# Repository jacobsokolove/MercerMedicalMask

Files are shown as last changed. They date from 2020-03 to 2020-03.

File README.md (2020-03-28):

# MercerMedicalMask
Reusable 3D printed face mask

Mercer School of Engineering faculty and students have been working to fabricate reusable 3D printed face masks for use by medical professionals in locations where PPE supplies, such as N95 masks, have been depleted by the sharp increase in patient numbers (**link to earlier press release).  

Today, Dr. Joanna Thomas and Mercer engineering student Jacob Sokolove, with the help of Coliseum Medical Center physicians and nurses, put their mask prototype through a fit test (https://www.osha.gov/video/respiratory_protection/fittesting_transcript.html) to confirm its effectiveness.  

The prototype passed with flying colors so Mercer plans to move forward fabricating masks and distributing to medical facilities and medical practitioners that have indicated a need for alternative PPE as a stop gap measure for employees until FDA approved PPE becomes available again. A link to more information on the mask materials and the mask STL files is located below.     

**This mask was designed with efficacy and the wearer’s safety in mind. We selected materials we believe to be biocompatible based on available product data sheets; however, these masks are not FDA tested or approved and Mercer cannot guarantee their efficacy or safety. Anyone who fabricates these or similar masks and/or wears the masks we produce does so at their own risk.

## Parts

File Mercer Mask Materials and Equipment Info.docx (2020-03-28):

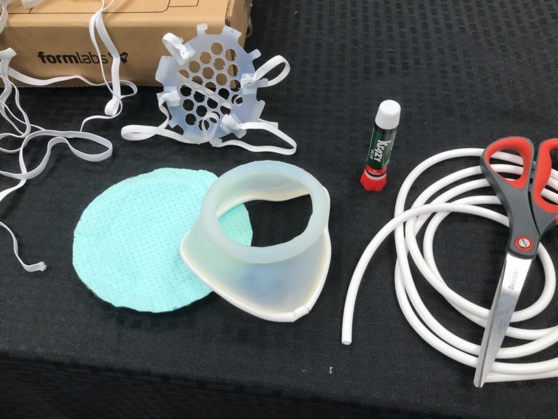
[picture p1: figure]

Mercer Mask Materials and Equipment Info

Formlabs Form2 or Form3 SLA printer

Formlabs Durable resin

405nm UV lights

Isopropanol

HEPA material

- This is what we are using https://www.homedepot.com/p/RIDGID-5-Layer-HEPA-Material-Pleated-Paper-Filter-for-Most-5-Gal-and-Larger-RIDGID-Wet-Dry-Shop-Vacuums-VF6000/100022800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

Elastic straps (strap holes in STL file are ~.3in w x .1in h)

Silicone rubber tubing

This is what we are using 1/8” ID, ¼” OD https://www.mcmaster.com/silicone-rubber-tubing

Our tested mask and clip were printed on a Formlabs Form2 SLA printer using Durable resin. We used .5 density for print supports with .5mm touchpoint size and mini rafts to attach to the print head. All prints were washed in >99% isopropanol for 20 min in a Form2 wash station. Prints were cured for at least 30min with 405nm lights.

The silicone rubber tubing was split open and pushed onto the face edge of the mask. A thin bead of super glue was used on the outward facing surface of the mask to secure the tubing to the mask.

HEPA material was cut into circles to match the mask opening.

Once the superglue was completely dry, the mask could be worn.

The printed Durable material can be cleaned with isopropanol, soap, and/or a bleach-based cleaning solution. Repeated exposures to isopropanol is expected to cause the material to become more brittle.

The HEPA material can be replaced as needed.

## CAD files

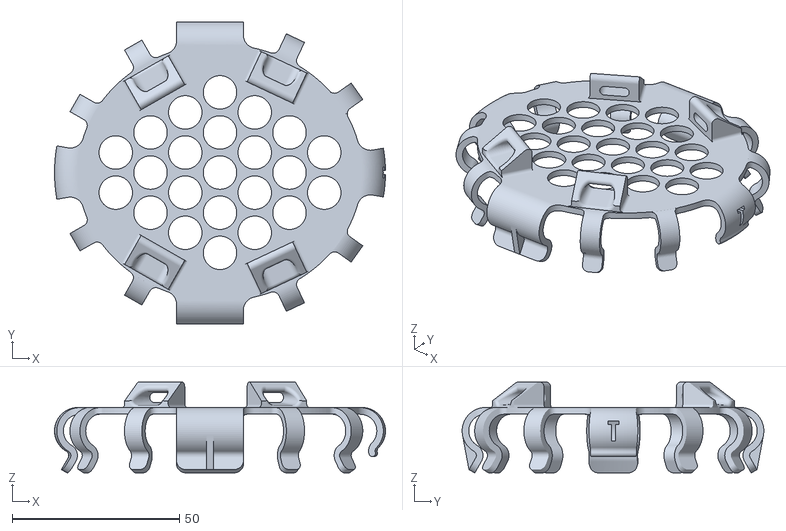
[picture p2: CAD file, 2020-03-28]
Mercer reusable 3D printed mask-clip.STL
99.0 x 90.2 x 27.2

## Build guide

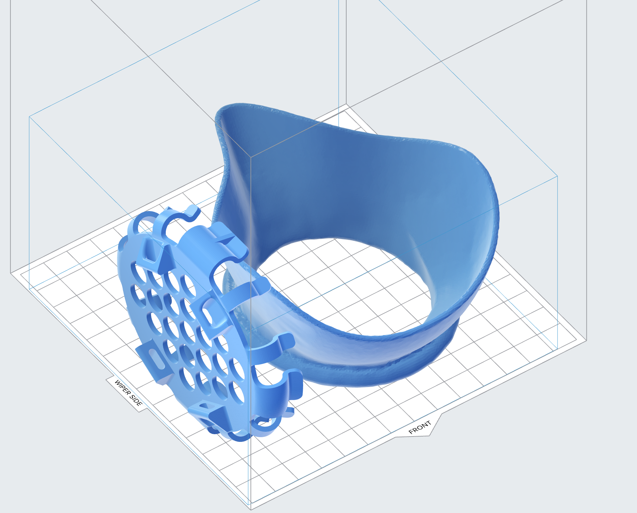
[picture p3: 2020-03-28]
Mercer reusable 3D printed mask - Preform.png
